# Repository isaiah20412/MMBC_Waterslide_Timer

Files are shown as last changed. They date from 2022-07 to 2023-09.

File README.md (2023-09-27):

# MMBC Waterslide Timer
## Project Writeup
>[!Note]
The following is **not** a proper Readme, but an excerpt of this project's documentation as found in the *Mountain Meadows Bible Camp Facilities Handbook*.

### Summary
The basic principle is relatively simple; a laser beam firing into a sensor at the top of the slide is broken when the rider passes through it. When the sensor registers the momentary lack of the laser, a stopwatch style timer is started. Another laser/sensor assembly is located at the bottom of the slide, just before the last section of slide, and it stops the timer when the rider passes through the final beam.

### Components
The brain of the operation is an Arduino Nano. (technically it is an Elegoo Nano - a much cheaper knockoff - but the two are essentially the same) The Arduino receives analog signals from the sensors, and when the values of those signals exceeds a given threshold, it starts or stops the timer, depending on which sensor the signal came from. A two part assembly consisting of a laser and a light sensor is responsible for detecting the presence of a rider at the start and end points of the slide. The lasers are small and inexpensive red laser diodes. The sensors are Light Detection Sensor modules that use a LDR (Light Dependent Resistor) to generate either an analog or digital signal. (I am using the analog output, as it allows for a higher amount of accuracy in determining whether the laser beam is or is not blocked by the body of a rider.)

### Operation
The top laser, top sensor, bottom laser, and bottom sensor are all enclosed in small black plastic project boxes (see figure #3). The Arduino itself is enclosed in a modified conduit termination box, which also houses a small OLED display and a pushbutton used to reset the timer after each run. Another black box acts as a junction box and merges the contents of three CAT5e cables into one. The entire system is powered  by an adjustable power supply, set to 9V DC, connected to yet another black box, which houses a Buck DC-DC Step-down Power Converter  that regulates the 9V to 5V. This box also contains a rocker switch used to turn the system's power on/off. Communication between all of these boxes is accomplished by varying lengths of CAT5e cable, with the cables that run to the sensors placed inside a run of 1/2" conduit.

### Additional Notes
In addition to all this, there is a modified Thermacell© bug repelling lamp (which no longer repels bugs) that now houses a cluster of three green LED's that will glow brightly when the timer has been reset and is currently stopped, and then dim once the timer has started. This allows a method of easy and reliable method of communication between the lifeguard and the people launching the rider.

The Arduino runs a relatively simple sketch (the official name for an Arduino code file), broken down into three major sections. Section #1 - Define variables. Section #2 - Setup (initialize display and go/no go light). Section #3 Main program: this is a three part loop, which continuously checks for a need to either start the timer, end it, or calculate the current time.

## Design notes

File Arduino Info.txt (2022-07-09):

After initializing this file for Arduino, use the contents of this file for the "arduino.json" file.

{
  "sketch": "MMBC_Waterslide_Timer.ino",
  "configuration": "usbstack=arduino,debug=off",
  "board": "Seeeduino:samd:seeed_XIAO_m0",
  "port": "COM8",
  "output": "build"
}

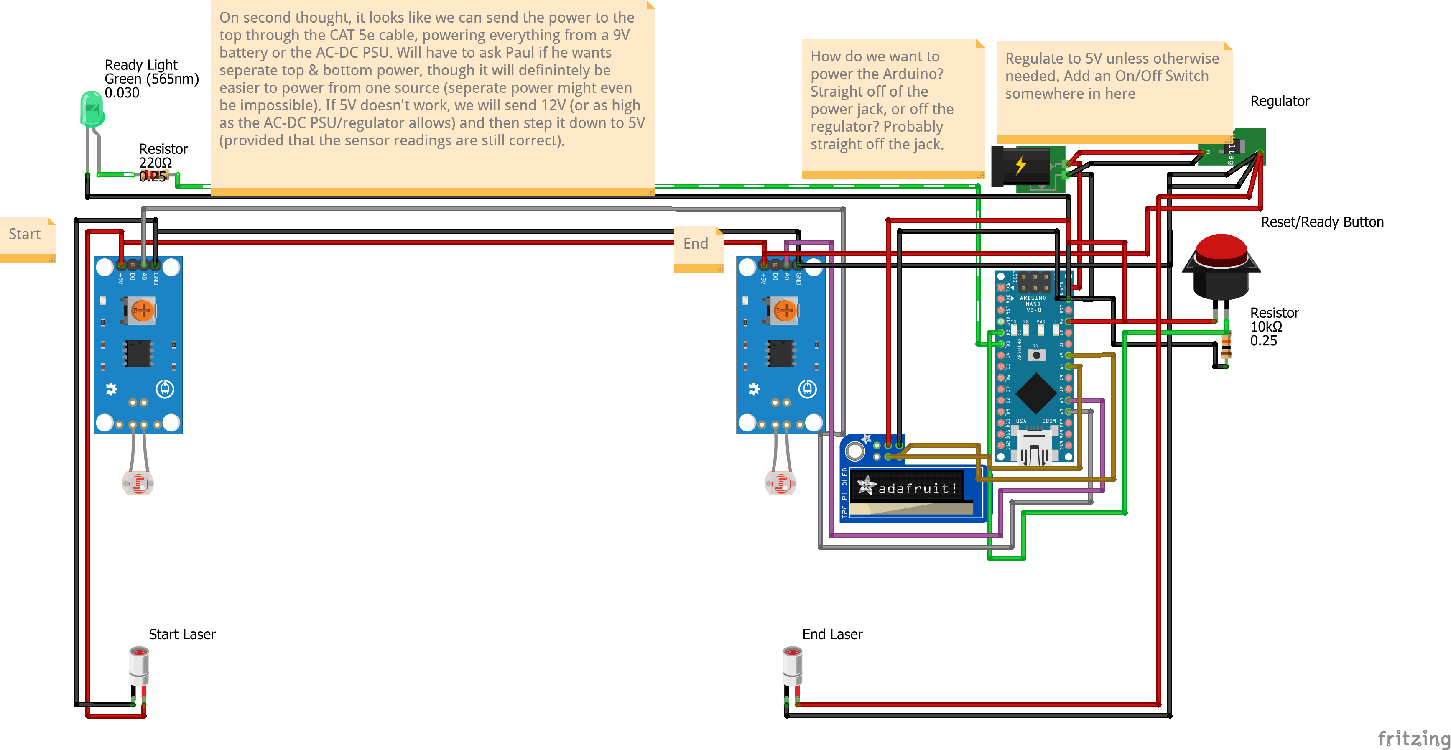
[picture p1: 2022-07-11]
Diagrams/MMBC Waterslide Timer_Graphic.png

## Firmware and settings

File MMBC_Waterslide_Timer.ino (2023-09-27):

//Section #1: Define variables

//Pins for various things
int resetButton = 2;
int startLaser = 0;
int stopLaser = 1;
int readyLED = 3;
int startTriggerValue;
int stopTriggerValue;


//Booleans for the program's running
bool r = false; // Variable for whether or not the timer is currently running.
bool showTime = false; //Variable to tell the program when to show the final time.
bool RTG = true; // Variable for whether or not the system has been reset and is good to go.

//Storage for the two numbers needed to calculate the total time of the run, as well as the final number
unsigned long start; // Start time (in milliseconds - based off the Arduino's internal clock, running since power on)
unsigned long finish; // End time (in milliseconds - based off the Arduino's internal clock, running since power on)
unsigned long elapsed; // How much time (in milliseconds) has actually gone by for the duration of the run.
unsigned long sampleStart; // Time when samples start to be taken.
unsigned long sampleStop; // Time when samples should stop being taken.
const long sampleInterval = 500; // Delay between each sample (Should usually be 500ms)
unsigned long previousMillis = 0;

#include <SPI.h>
#include <Wire.h>
#include <Adafruit_GFX.h>
#include <Adafruit_SSD1306.h>

#define SCREEN_WIDTH 128 // OLED display width, in pixels
#define SCREEN_HEIGHT 32 // OLED display height, in pixels

#define OLED_RESET     -1 // Reset pin # (or -1 if sharing Arduino reset pin)
Adafruit_SSD1306 display(SCREEN_WIDTH, SCREEN_HEIGHT, &Wire, OLED_RESET);

//Section #2: Setup

void setup() {
  // put your setup code here, to run once:

  /*
    pinMode(startButton, INPUT);
    pinMode(stopButton, INPUT);
 
  */
   Serial.begin(115200);

  pinMode(readyLED, OUTPUT);

  // Initialize Display
  display.begin(SSD1306_SWITCHCAPVCC, 0x3C);
  display.clearDisplay();
  display.setTextSize(3); // Draw 2X-scale text
  display.setTextColor(WHITE);
  display.print("Hello!");
  display.display();
  delay(1000);

  //Display Loading Screen
  display.clearDisplay();
  display.setTextSize(1);
  display.setTextColor(WHITE);
  display.setCursor(25, 0);
  display.print("Please Wait");
  display.setTextSize(1);
  display.setCursor(11, 15);
  display.print("Sampling Lasers");
  display.display();
  

  // Get average laser light levels
  startTriggerValue = Sensor_Sample(startLaser);
  Serial.print("Start Laser Threshold: ");
  Serial.println(startTriggerValue);
  stopTriggerValue = Sensor_Sample(stopLaser);
  Serial.print("Stop Laser Threshold: ");
  Serial.println(stopTriggerValue);

  // Tell the user that we're ready
  display.clearDisplay();
  display.setTextSize(2); // Draw 2X-scale text
  display.setCursor(45, 0);
  display.print("MMBC");
  display.setTextSize(1);
  display.setCursor(11, 15);
  display.print("Waterslide is ready");
  display.display();
  delay(1500);
  display.clearDisplay();
  display.setTextSize(3);
  display.setCursor(0, 0);
  display.print("0:00:00");
  display.display();
  digitalWrite(readyLED, HIGH);
}

//Section #3: Main program.

void loop() {
  // put your main code here, to run repeatedly:
  checkStart();
  checkStop();
  displayTime();
}

//Function Declarations
int Sensor_Sample(int sPin) {
  sampleStart = millis();
  int numSamples = 0;
  int sampleValue = 0;
    
  for (int i = 0; i < 10;) {
    unsigned long currentMillis = millis();
    if (currentMillis - previousMillis >= sampleInterval) {
      previousMillis = currentMillis;
      sampleValue = sampleValue + analogRead(sPin);
      //Serial.println(i); //Use when debugging
      i ++;
      }
    } 
  
  sampleValue = sampleValue / 10;    // average
  return sampleValue;
}

void checkStart() {
  if (digitalRead(resetButton) == HIGH && r == false) {
    RTG = true;
    display.clearDisplay();
    display.setTextSize(3);
    display.setCursor(0, 0);
    display.print("0:00:00");
    display.display();
    digitalWrite(readyLED, HIGH);
  }

  int startThreshold = startTriggerValue + 100;
  
  if (analogRead(startLaser) > startThreshold && r == false && RTG == true) {
    r = true;
    RTG = false;
    start = millis();
    digitalWrite(readyLED, LOW);
  }
}

void checkStop() {

  int stopThreshold = stopTriggerValue + 100;

  if (analogRead(stopLaser) > stopThreshold && r == true) {
    r = false;
    finish = millis();
    showTime = true;
  }
}

void displayTime() {
  unsigned long current;
  unsigned long currentTime;
  int seconds = 0;
  seconds = elapsed % 1000;
  while (r == true) {
    /*
    // For debugging only
      current = millis();
      currentTime = current - start;
      Serial.println(currentTime);
    */
    checkStop();
    current = millis();
    if (showTime == false) {
      currentTime = current - start;
      // declare variables
      float h, m, s, ms;
      unsigned long over;

      // MATH time!!!
      h = int(currentTime / 3600000);
      over = currentTime % 3600000;
      m = int(over / 60000);
      over = over % 60000;
      s = float(over / 1000);
      ms = over % 1000;
      
      display.clearDisplay();
      display.setTextSize(3); // Draw 2X-scale text
      display.setTextColor(WHITE);
      display.setCursor(0, 0);
      display.print(m, 0);
      display.print(":");
      display.print(s, 0);
      display.print(":");
      display.print(ms, 0);
      display.display();
    }

    while (r == false) {
      checkStart();
      if (showTime == true) {
        elapsed = finish - start;
        // declare variables
        float h, m, s, ms;
        unsigned long over;

        // MATH time!!!
        h = int(elapsed / 3600000);
        over = elapsed % 3600000;
        m = int(over / 60000);
        over = over % 60000;
        s = float(over / 1000);
        ms = over % 1000;
        
        display.clearDisplay();
        display.setTextSize(3); // Draw 2X-scale text
        display.setTextColor(WHITE);
        display.setCursor(0, 0);
        display.print(m, 0);
        display.print(":");
        display.print(s, 0);
        display.print(":");
        display.print(ms, 0);
        display.display();

        showTime = false;
      }
    }
  }
}

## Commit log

2022-07-09 Added Diagrams (For real this time)
    [MMBC Waterslide Timer.fzz]
2022-07-09 Updated .gitignore Enabled tracking on the "arduino.json" file. (Hopefully)
2022-07-09 "Arduino Info.txt" Added a file with some basic Arduino setup snippets.
2022-07-09 Updated .gitignore (Hopefully) enabled syncing of the arduino.json file, but nothing else!
2022-07-11 Updated wiring diagram
    [MMBC Waterslide Timer.fzz]
2022-07-11 Updated wiring diagram & Re-exported .png file
    [MMBC Waterslide Timer.fzz]
2022-07-11 Started writing a function for sensor sampling.
2022-07-11 Basic idea and code for the Sensor_Sample function
2022-07-12 Sensor_Sample function success!!! Finally ironed out all the kinks in the sampling function. Also started removing old code scraps.
2023-06-14 Start/stop Sampling Debugging Added print statements to output the start and stop trigger values to the serial monitor.
2023-06-16 Updated Diagrams
    [MMBC Waterslide Timer_Bottom.fzz]
